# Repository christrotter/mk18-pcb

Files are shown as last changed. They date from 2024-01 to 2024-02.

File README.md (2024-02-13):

# PRODUCTION UPDATE - SUPERSEDED
This has been superseded by the rev2 of this board: [mk19](https://github.com/christrotter/mk19-pcb)

Many lessons learned.  Chief among them - it works!  We were able to prove out the shift register method.

## Things to fix
- dpad col usage; rethink how to make the dpad customizable e.g. rkjxt change-of-mind
- bad tft pinout; ordering wrong
- tft should be 0.5mm 8-pin ffc, not jst
- missing resistor arrays, 10k
- if there is a pin that could be reconfigured, ensure there is a breakout for that?
- move cyboard to edge of board
- cyboard breakout pcbs...seriously consider this; the cable lengths are super short
- main to a larger ffc cable
- per-key 0.3mm extenders pcbs...?
- change macropad vertical to edge-of-board flat FFC
- 90-deg jst, how will this help?
- and how would we make it fit?  where would things work out best to avoid the pcb capture?
- really need to make this happen
- bigger solder pads; or rather, jumpers! for the handedness, power bypass
- re-think the led bypass stuff...
- the whole bypass thing doesn’t work like i’d thought
- spare gpio breakouts should be 2.54 spaced
- what would it look like to have dual TFT?
- indicator breakout
- really needs to be DI/DO pairs per block of LEDs
- main slats
- small slats
- indicators
- then dedicated power breakouts for each
- 5v/3.3v/gnd for debug
- 5v/gnd x3 for leds
- there’s something i thought of that i didn’t write down and here we are…
- need to provide for power input
- GeorgeN suggests VSYS, not VBUS
- section 4.5 of pico datasheet
- do we want a dedicated USB power in?

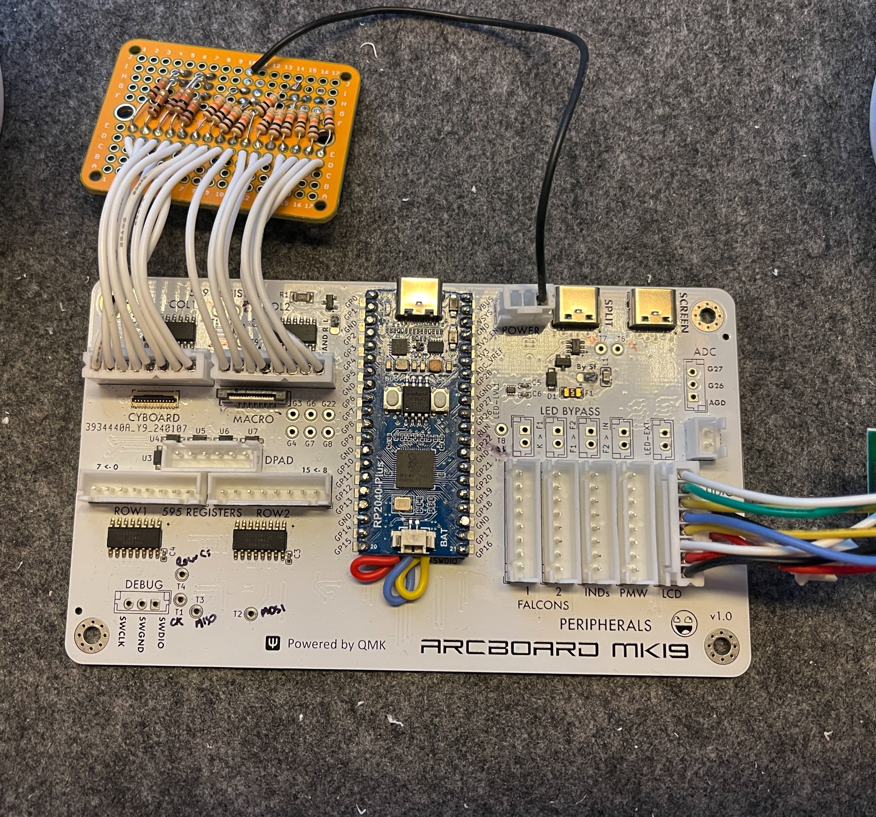
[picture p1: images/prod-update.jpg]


# mk18-pcb
The antithesis of 'keep it simple, stupid' - all the features, all the time.

Do you need to use the Cyboard flex-pcb system?  Multiple Falcon pcbs?  SPI devices?  32 pins for rows/cols?  Perhaps enough RGB to illumine your entire home?  Audio?  ADC?  Reset switch? Power and debug breakouts?  And use an existing RP Pico to do it?

Probably not, which is why I had to design my own pcb.  So here it is...

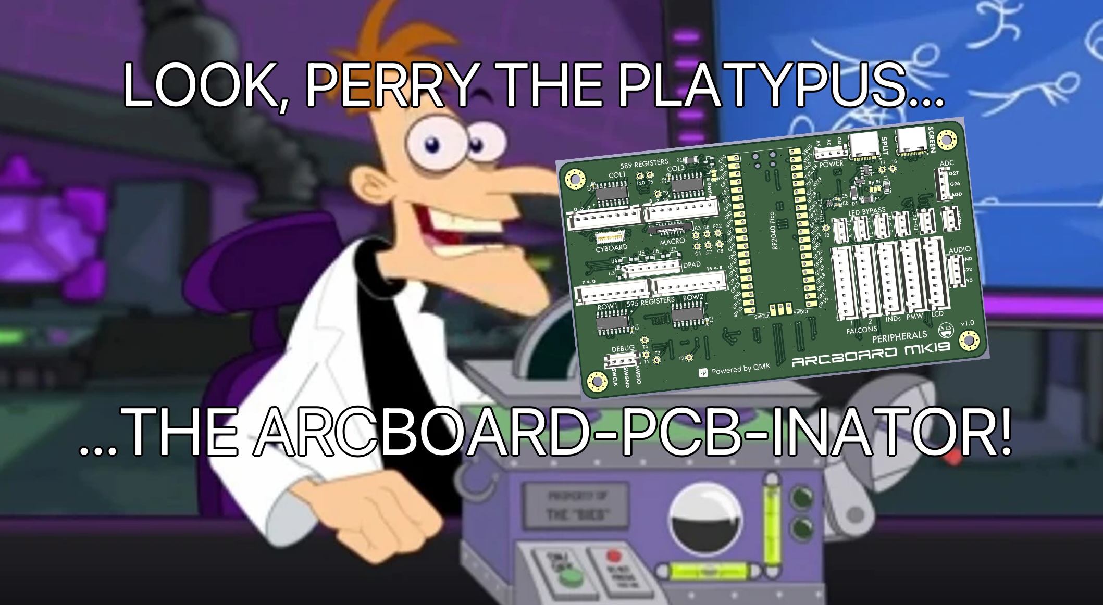
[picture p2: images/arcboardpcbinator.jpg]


# design goals
- Provide a re-usable platform for the arcboards that includes all of the normal functions
- Make it possible to use the Cyboard flex-pcb system
- Minimize pin usage by moving cols/rows over to shift registers
- Reduce the amount of fiddly soldering and wire stripping a normal hand-wire requires of you
- usb-c interconnects

## feature details
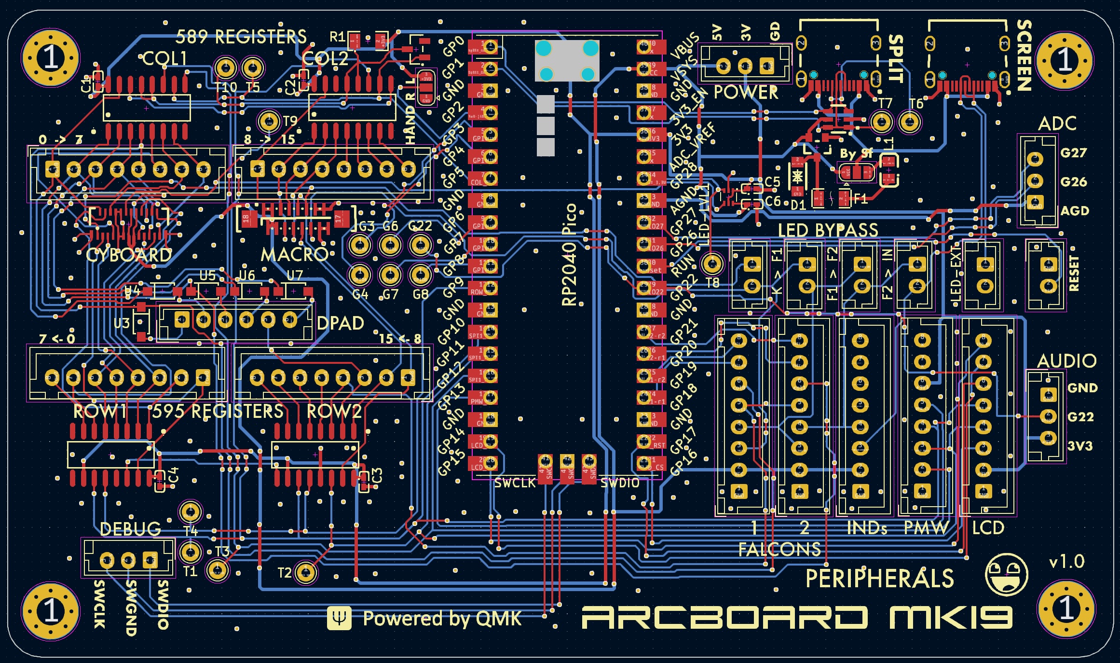
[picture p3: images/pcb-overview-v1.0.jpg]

- Raspberry PI Pico (RP2040) footprint - just add pin headers and solder away - or, solder right to pads
- keys provided through the Cyboard flex-pcb: https://www.cyboard.digital/product-page/dactyl-flex-pcbs
 - or, JST-XH 2.54 headers
- macropad using Cyboard flex-pcb keys, custom breakout pcb: https://github.com/christrotter/macropad-pcb (0.5mm pitch 16-pin FFC cable)
 - vertical FFC connector
- dpad using custom breakout pcb: https://github.com/christrotter/5way-pcb
 - diodes are configured for ROW2COL
- usb-c split connector w. tzarc-grade voltage protection
 - buuut included a solder pad jumper to bypass if needed
- split-handedness pin
- SPI breakouts
  - PMW33xx
  - LCD (e.g. GC9A01)
  - shift registers (595 for rows, 589 for cols)
- pin breakouts
 - power, debug, ADC, audio, reset
 - remaining GPIO pins
 - test points (SPI pins, serial pins, WS2818 before/after level shifting)
- led breakouts w. bypasses
 - keys
 - 2x falcon pcbs
 - indicator strip
 - screen-mounted external indicators via usb-c
 - pin for whatever else you want to add to the chain

## pcb features
- two-layer pcb w. dual ground planes tied w. vias
- components configured as per datasheets
- bypass capacitors!
- care taken to avoid power running alongside signal for too long

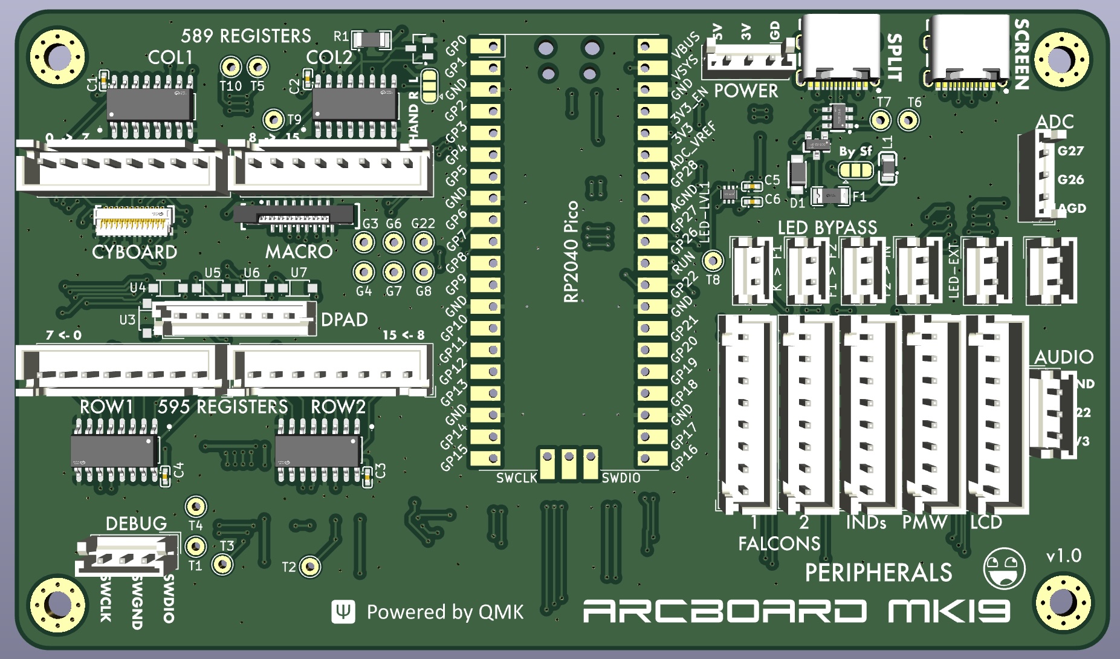
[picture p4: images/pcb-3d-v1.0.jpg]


# schematic overview
## mcu
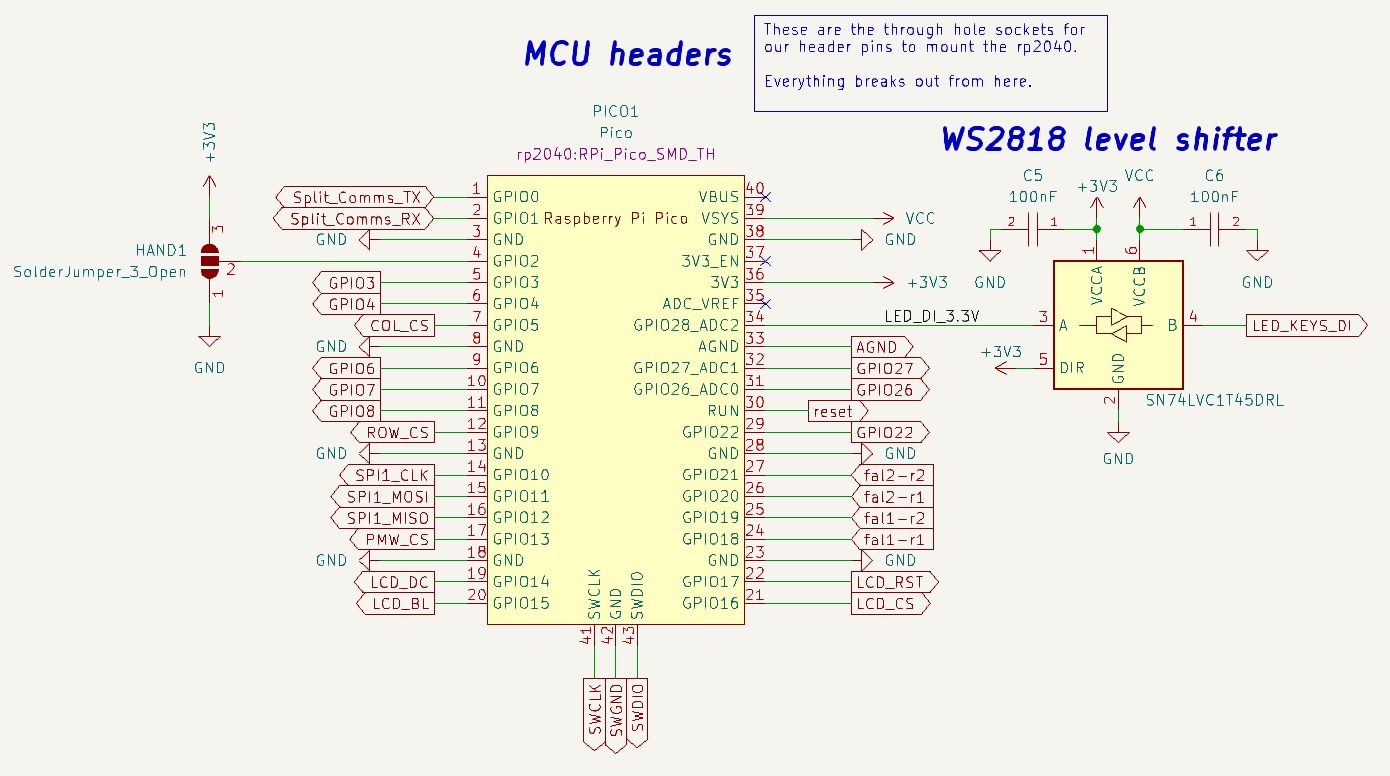
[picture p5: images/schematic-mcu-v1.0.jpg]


## keys
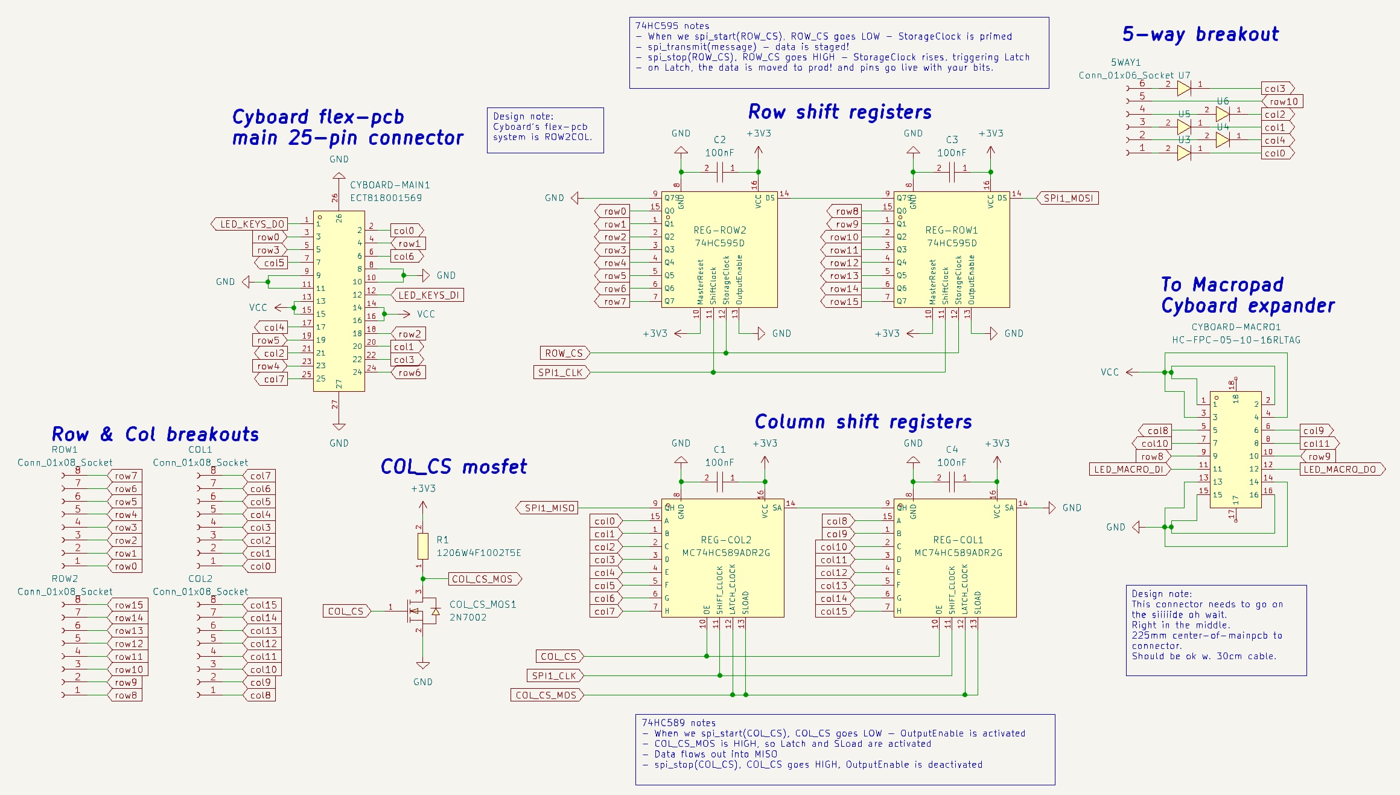
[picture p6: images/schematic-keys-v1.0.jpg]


## peripherals
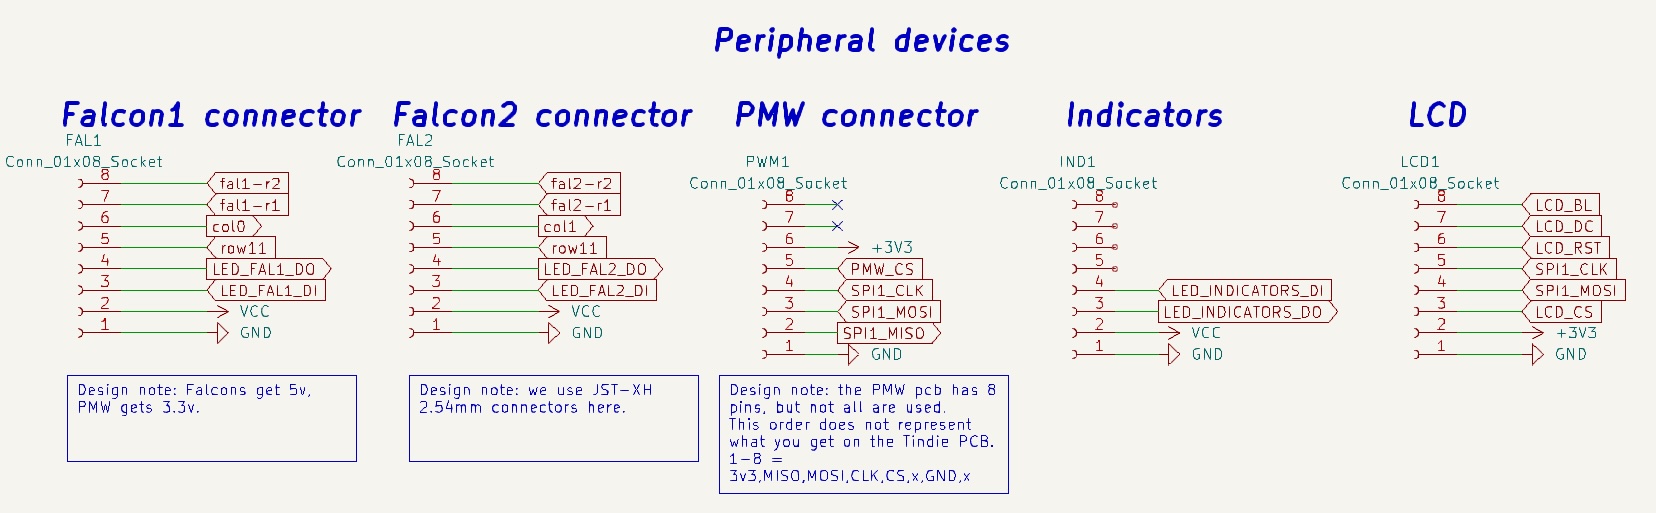
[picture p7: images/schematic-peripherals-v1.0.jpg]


## usb connections
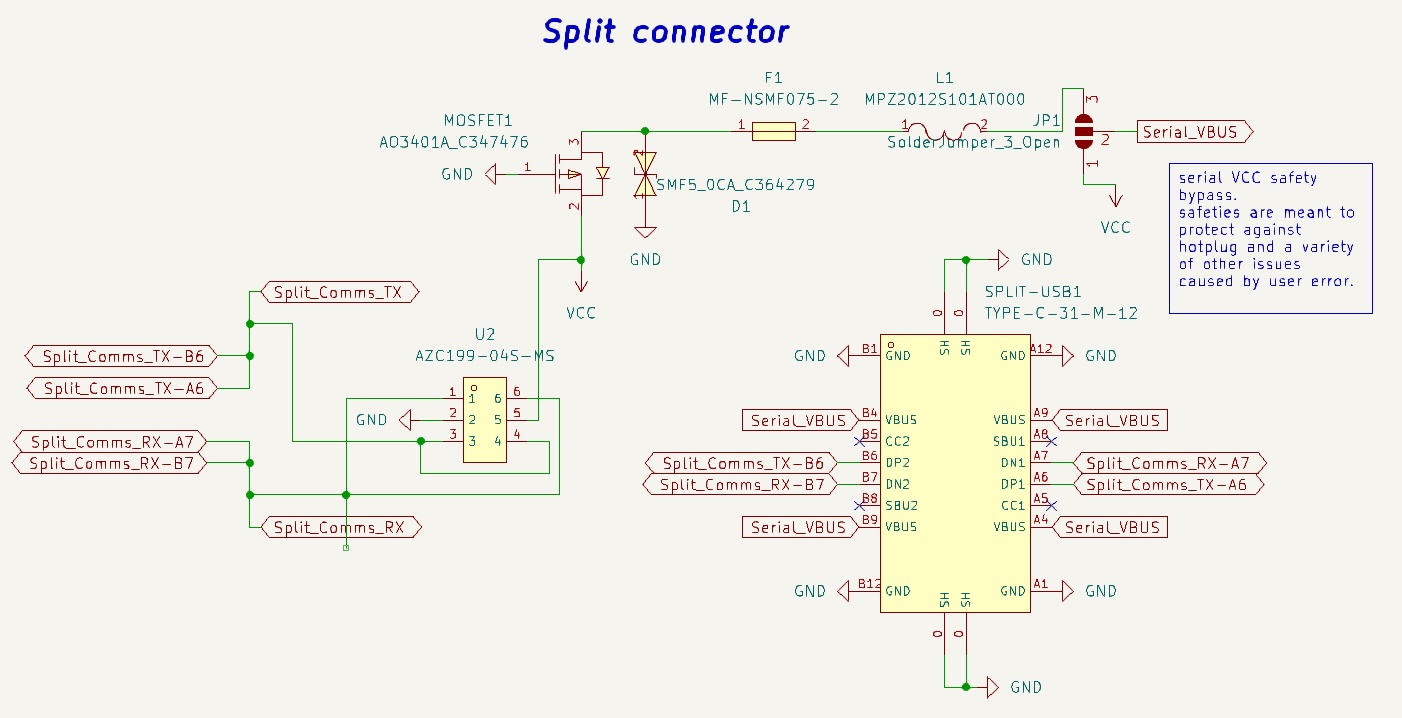
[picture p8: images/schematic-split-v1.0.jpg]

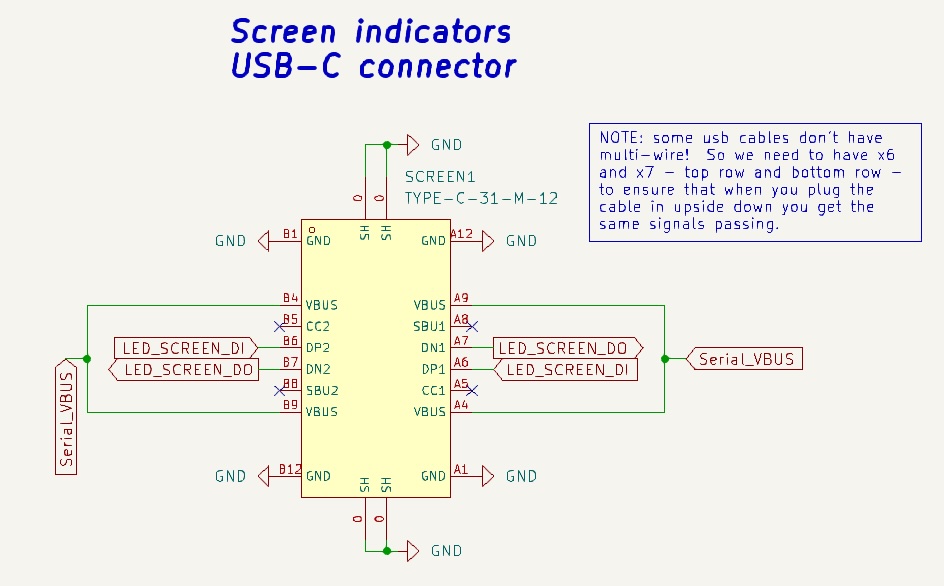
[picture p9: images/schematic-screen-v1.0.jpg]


## breakouts
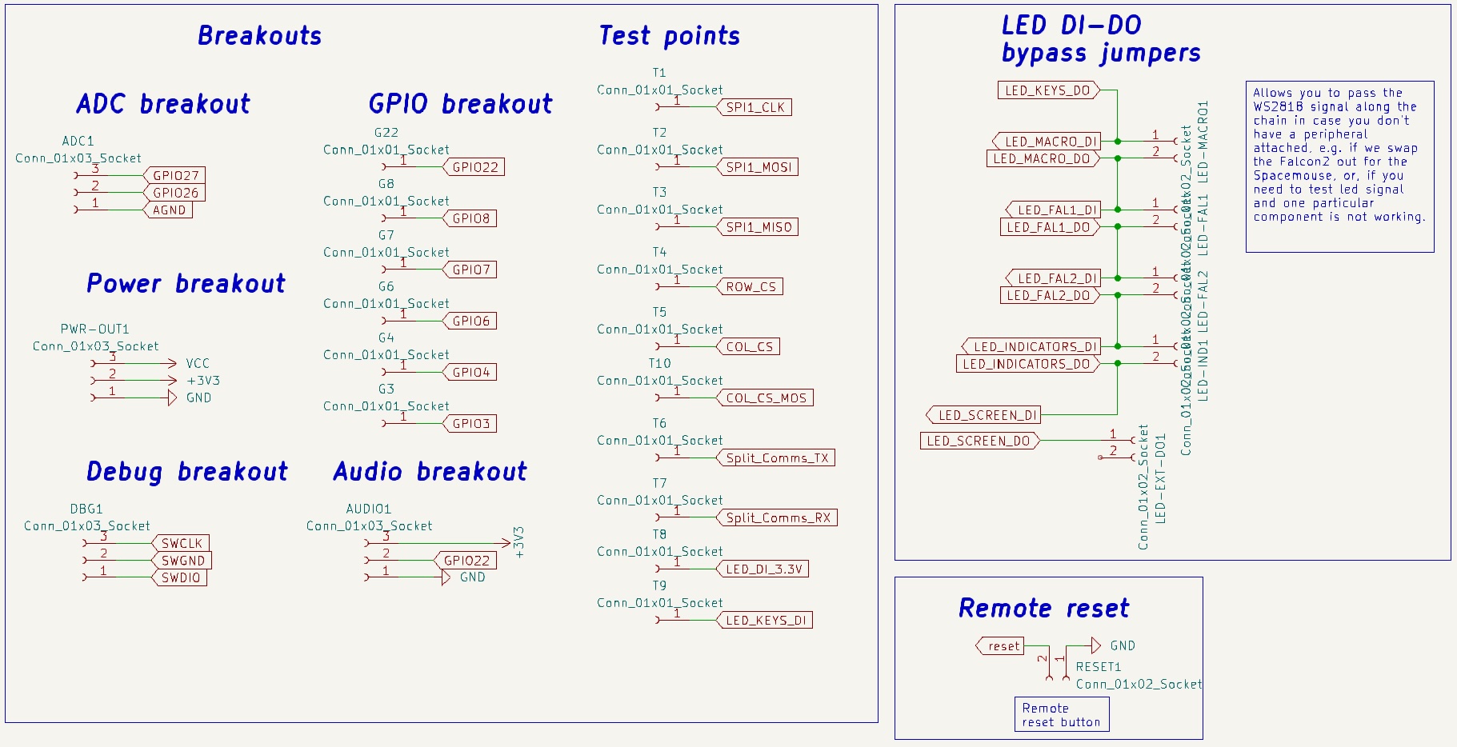
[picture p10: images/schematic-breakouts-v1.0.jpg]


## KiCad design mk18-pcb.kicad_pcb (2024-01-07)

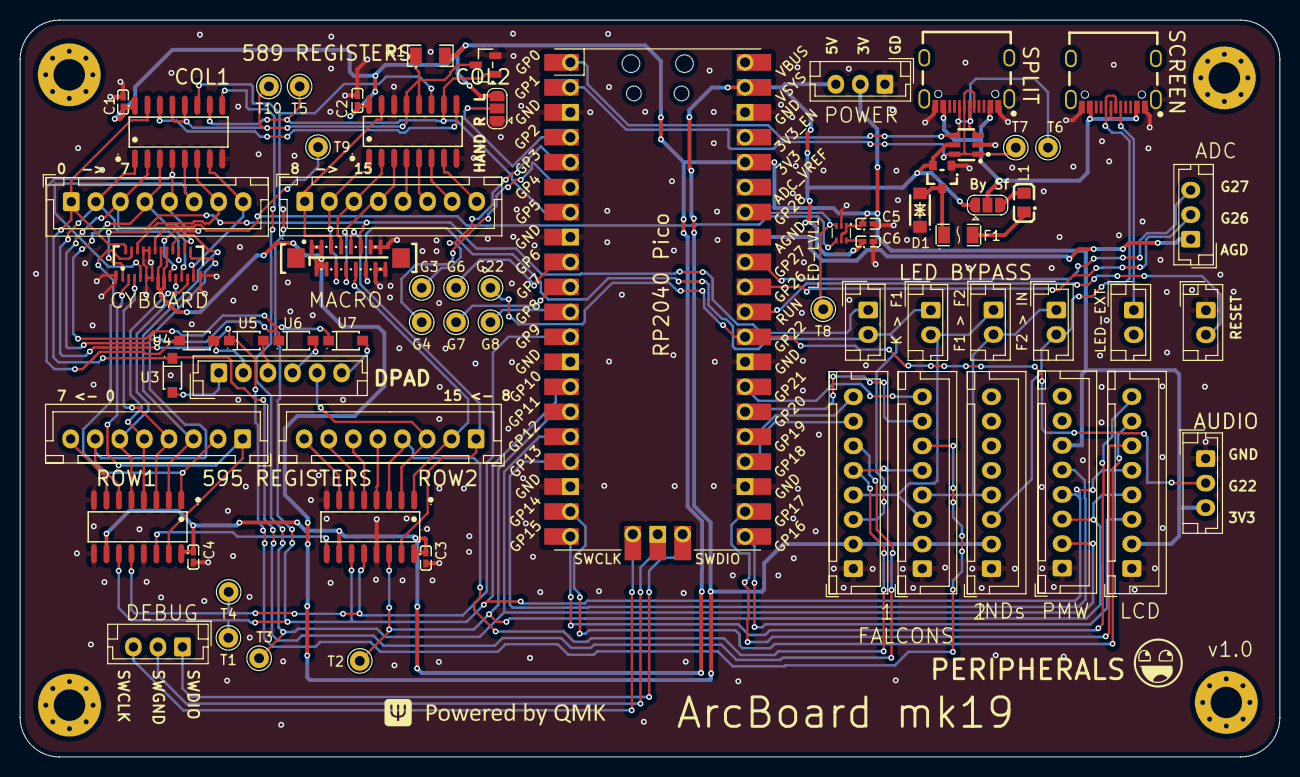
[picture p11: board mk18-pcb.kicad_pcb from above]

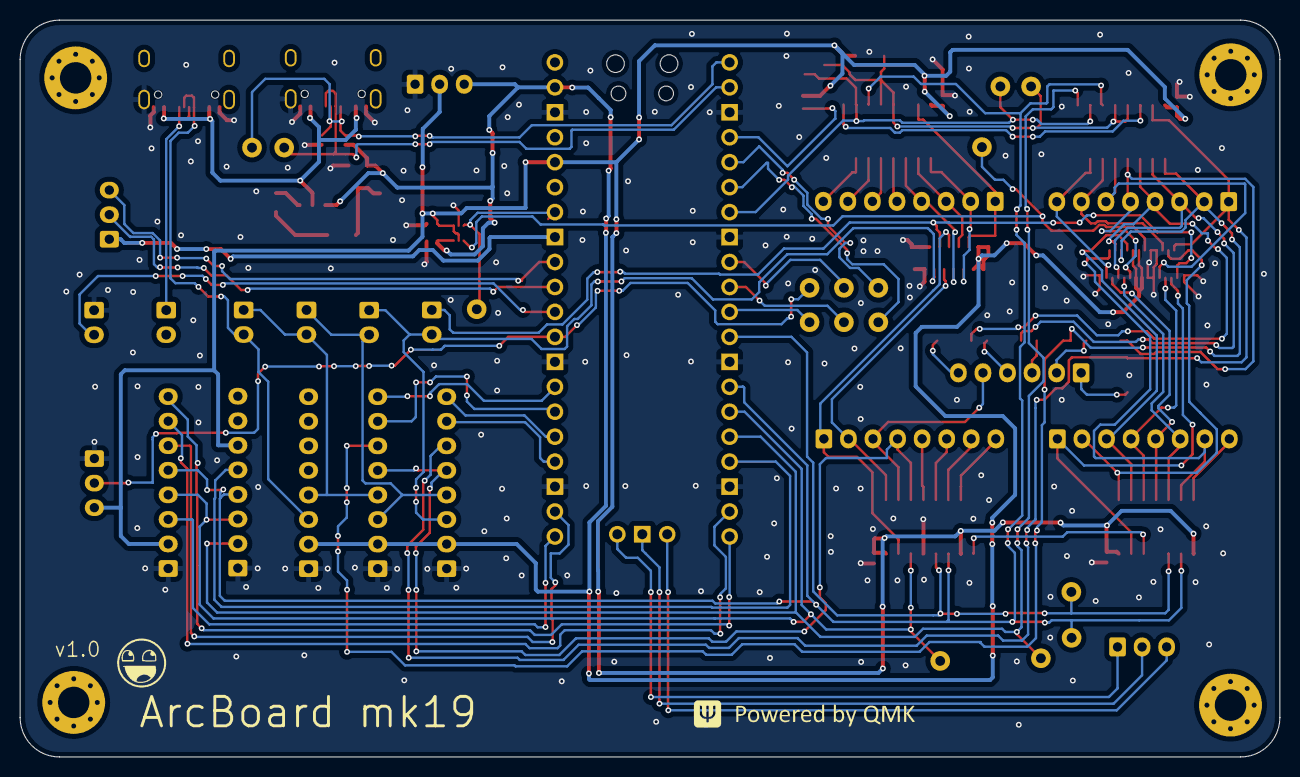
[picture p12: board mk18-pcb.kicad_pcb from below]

Board: 2 copper layers, 128.2 x 75.0 mm, 74 parts (2 on the bottom side), 85 nets.

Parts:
5WAY1: Conn_01x06_Socket; JST_EH_B6B-EH-A_1x06_P2.50mm_Vertical
ADC1: Conn_01x03_Socket; JST_EH_B3B-EH-A_1x03_P2.50mm_Vertical
AUDIO1: Conn_01x03_Socket; JST_EH_B3B-EH-A_1x03_P2.50mm_Vertical
C1, C2, C3, C4, C5, C6: 100nF; C0402
COL1, COL2: Conn_01x08_Socket; JST_XH_B8B-XH-A_1x08_P2.50mm_Vertical
COL_CS_MOS1: 2N7002; SOT-23-3_L2.9-W1.3-P1.90-LS2.4-BR
CYBOARD-MACRO1: HC-FPC-05-10-16RLTAG; FPC-SMD_16P-P0.50_HDGC_0.5K-A-16PBF
CYBOARD-MAIN1: ECT818001569; FPC-SMD_ECT818001569
D1: SMF5_0CA_C364279; SOD-123FL_L2.8-W1.8-LS3.7-BI
DBG1: Conn_01x03_Socket; JST_EH_B3B-EH-A_1x03_P2.50mm_Vertical
F1: MF-NSMF075-2; F1206
FAL1, FAL2: Conn_01x08_Socket; JST_XH_B8B-XH-A_1x08_P2.50mm_Vertical
G3, G4, G6, G7, G8, G22: Conn_01x01_Socket; Pin_D1.0mm_L10.0mm
H1, H2, H3, H4: MountingHole; MountingHole_3.2mm_M3_Pad_Via
HAND1: SolderJumper_3_Open; SolderJumper-3_P1.3mm_Open_RoundedPad1.0x1.5mm
IND1: Conn_01x08_Socket; JST_XH_B8B-XH-A_1x08_P2.50mm_Vertical
JP1: SolderJumper_3_Open; SolderJumper-3_P1.3mm_Open_RoundedPad1.0x1.5mm
L1: MPZ2012S101AT000; L0805
LCD1: Conn_01x08_Socket; JST_XH_B8B-XH-A_1x08_P2.50mm_Vertical
LED-EXT-DO1: Conn_01x02_Socket; JST_EH_B2B-EH-A_1x02_P2.50mm_Vertical
LED-FAL1, LED-FAL2: Conn_01x02_Socket; JST_EH_B2B-EH-A_1x02_P2.50mm_Vertical
LED-IND1: Conn_01x02_Socket; JST_EH_B2B-EH-A_1x02_P2.50mm_Vertical
LED-LVL1: SN74LVC1T45DRL; SOT-563_L1.6-W1.2-P0.50-LS1.6-BR
LED-MACRO1: Conn_01x02_Socket; JST_EH_B2B-EH-A_1x02_P2.50mm_Vertical
LOGO1, LOGO2: **REF; awesome-logo
LOGO3, LOGO4: **REF; qmk-lite
MOSFET1: AO3401A_C347476; SOT-23_L2.9-W1.3-P1.90-LS2.4-BR
PICO1: Pico; RPi_Pico_SMD_TH
PWM1: Conn_01x08_Socket; JST_XH_B8B-XH-A_1x08_P2.50mm_Vertical
PWR-OUT1: Conn_01x03_Socket; JST_EH_B3B-EH-A_1x03_P2.50mm_Vertical
R1: 1206W4F1002T5E; R1206
REG-COL1, REG-COL2: MC74HC589ADR2G; SOIC-16_L9.9-W3.9-P1.27-LS6.0-BL
REG-ROW1, REG-ROW2: 74HC595D; SOIC-16_L9.9-W3.9-P1.27-LS6.0-BL
RESET1: Conn_01x02_Socket; JST_EH_B2B-EH-A_1x02_P2.50mm_Vertical
ROW1, ROW2: Conn_01x08_Socket; JST_XH_B8B-XH-A_1x08_P2.50mm_Vertical
SCREEN1: TYPE-C-31-M-12; USB-C_SMD-TYPE-C-31-M-12
SPLIT-USB1: TYPE-C-31-M-12; USB-C_SMD-TYPE-C-31-M-12
T1, T2, T3, T4, T5, T6, T7, T8, T9, T10: Conn_01x01_Socket; Pin_D1.0mm_L10.0mm
U2: AZC199-04S-MS; TSOT-23-6_L2.9-W1.6-P0.95-LS2.8-BL
U3, U4, U5, U6, U7: 1N4148W_C81598; SOD-123F_L2.7-W1.6-LS3.8-RD

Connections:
+3V3: AUDIO1.3, C1.1, C2.1, C3.1, C4.1, C5.1, HAND1.3 (B), LCD1.2, LED-LVL1.1 (VCCA), LED-LVL1.5 (DIR), PICO1.36 (3V3), PWM1.6, PWR-OUT1.2, R1.2, REG-COL1.16 (VCC), REG-COL2.16 (VCC), REG-ROW1.10 (MasterReset), REG-ROW1.16 (VCC), REG-ROW2.10 (MasterReset), REG-ROW2.16 (VCC)
AGND: ADC1.1, PICO1.33 (AGND)
COL_CS: COL_CS_MOS1.1 (G), PICO1.7 (GPIO5), REG-COL1.10 (OE), REG-COL2.10 (OE), T5.1
COL_CS_MOS: COL_CS_MOS1.3 (D), R1.1, REG-COL1.12 (LATCH_CLOCK), REG-COL1.13 (SLOAD), REG-COL2.12 (LATCH_CLOCK), REG-COL2.13 (SLOAD), T10.1
GND: AUDIO1.1, C1.2, C2.2, C3.2, C4.2, C5.2, C6.2, COL_CS_MOS1.2 (S), CYBOARD-MACRO1.13, CYBOARD-MACRO1.14, CYBOARD-MACRO1.15, CYBOARD-MACRO1.16, CYBOARD-MAIN1.8, CYBOARD-MAIN1.9, CYBOARD-MAIN1.10, CYBOARD-MAIN1.11, CYBOARD-MAIN1.26, CYBOARD-MAIN1.27, D1.1 (K), FAL1.1, FAL2.1, HAND1.1 (A), IND1.1, LCD1.1, LED-LVL1.2 (GND), MOSFET1.1 (G), PICO1.3 (GND), PICO1.8 (GND), PICO1.13 (GND), PICO1.18 (GND), PICO1.23 (GND), PICO1.28 (GND), PICO1.38 (GND), PWM1.1, PWR-OUT1.1, REG-COL1.8 (GND), REG-COL1.14 (SA), REG-COL2.8 (GND), REG-ROW1.8 (GND), REG-ROW1.13 (OutputEnable), REG-ROW2.8 (GND), REG-ROW2.9 (Q7S), REG-ROW2.13 (OutputEnable), RESET1.1, SCREEN1.0 (SH), SCREEN1.A1 (GND), SCREEN1.A12 (GND), SCREEN1.B1 (GND), SCREEN1.B12 (GND), SPLIT-USB1.0 (SH), SPLIT-USB1.A1 (GND), SPLIT-USB1.A12 (GND), SPLIT-USB1.B1 (GND), SPLIT-USB1.B12 (GND), U2.2
GPIO3: G3.1, PICO1.5 (GPIO3)
GPIO4: G4.1, PICO1.6 (GPIO4)
GPIO6: G6.1, PICO1.9 (GPIO6)
GPIO7: G7.1, PICO1.10 (GPIO7)
GPIO8: G8.1, PICO1.11 (GPIO8)
GPIO22: AUDIO1.2, G22.1, PICO1.29 (GPIO22)
GPIO26: ADC1.2, PICO1.31 (GPIO26_ADC0)
GPIO27: ADC1.3, PICO1.32 (GPIO27_ADC1)
LCD_BL: LCD1.8, PICO1.20 (GPIO15)
LCD_CS: LCD1.3, PICO1.21 (GPIO16)
LCD_DC: LCD1.7, PICO1.19 (GPIO14)
LCD_RST: LCD1.6, PICO1.22 (GPIO17)
LED_DI_3.3V: LED-LVL1.3 (A), PICO1.34 (GPIO28_ADC2), T8.1
LED_FAL1_DI: CYBOARD-MACRO1.12, FAL1.3, LED-FAL1.1, LED-MACRO1.2
LED_FAL1_DO: FAL1.4, FAL2.3, LED-FAL1.2, LED-FAL2.1
LED_FAL2_DO: FAL2.4, IND1.4, LED-FAL2.2, LED-IND1.1
LED_INDICATORS_DO: IND1.3, LED-IND1.2, SCREEN1.A6 (DP1), SCREEN1.B6 (DP2)
LED_KEYS_DI: CYBOARD-MAIN1.12, LED-LVL1.4 (B), T9.1
LED_KEYS_DO: CYBOARD-MACRO1.11, CYBOARD-MAIN1.1, LED-MACRO1.1
LED_SCREEN_DO: LED-EXT-DO1.1, SCREEN1.A7 (DN1), SCREEN1.B7 (DN2)
unnamed: 5WAY1.1, U3.2 (A)
unnamed: 5WAY1.2, U4.2 (A)
unnamed: 5WAY1.3, U5.2 (A)
unnamed: 5WAY1.4, U6.2 (A)
unnamed: 5WAY1.6, U7.2 (A)
unnamed: D1.2 (A), F1.1, MOSFET1.3 (D)
unnamed: F1.2, L1.1
unnamed: HAND1.2 (C), PICO1.4 (GPIO2)
unnamed: JP1.3 (B), L1.2
unnamed: REG-COL1.9 (QH), REG-COL2.14 (SA)
unnamed: REG-ROW1.9 (Q7S), REG-ROW2.14 (DS)
PMW_CS: PICO1.17 (GPIO13), PWM1.5
ROW_CS: PICO1.12 (GPIO9), REG-ROW1.12 (StorageClock), REG-ROW2.12 (StorageClock), T4.1
SPI1_CLK: LCD1.5, PICO1.14 (GPIO10), PWM1.4, REG-COL1.11 (SHIFT_CLOCK), REG-COL2.11 (SHIFT_CLOCK), REG-ROW1.11 (ShiftClock), REG-ROW2.11 (ShiftClock), T1.1
SPI1_MISO: PICO1.16 (GPIO12), PWM1.2, REG-COL2.9 (QH), T3.1
SPI1_MOSI: LCD1.4, PICO1.15 (GPIO11), PWM1.3, REG-ROW1.14 (DS), T2.1
SWCLK: DBG1.3, PICO1.41 (SWCLK)
SWDIO: DBG1.1, PICO1.43 (SWDIO)
SWGND: DBG1.2, PICO1.42 (GND)
Serial_VBUS: JP1.2 (C), SCREEN1.A4 (VBUS), SCREEN1.A9 (VBUS), SCREEN1.B4 (VBUS), SCREEN1.B9 (VBUS), SPLIT-USB1.A4 (VBUS), SPLIT-USB1.A9 (VBUS), SPLIT-USB1.B4 (VBUS), SPLIT-USB1.B9 (VBUS)
Split_Comms_RX: PICO1.2 (GPIO1), SPLIT-USB1.A7 (DN1), SPLIT-USB1.B7 (DN2), T7.1, U2.1, U2.6
Split_Comms_TX: PICO1.1 (GPIO0), SPLIT-USB1.A6 (DP1), SPLIT-USB1.B6 (DP2), T6.1, U2.3, U2.4
VCC: C6.1, CYBOARD-MACRO1.1, CYBOARD-MACRO1.2, CYBOARD-MACRO1.3, CYBOARD-MACRO1.4, CYBOARD-MAIN1.13, CYBOARD-MAIN1.14, CYBOARD-MAIN1.15, CYBOARD-MAIN1.16, FAL1.2, FAL2.2, IND1.2, JP1.1 (A), LED-LVL1.6 (VCCB), MOSFET1.2 (S), PICO1.39 (VSYS), PWR-OUT1.3, U2.5
col0: COL1.1, CYBOARD-MAIN1.2, FAL1.6, REG-COL2.15 (A), U3.1 (K)
col1: COL1.2, CYBOARD-MAIN1.20, FAL2.6, REG-COL2.1 (B), U5.1 (K)
col2: COL1.3, CYBOARD-MAIN1.21, REG-COL2.2 (C), U6.1 (K)
col3: COL1.4, CYBOARD-MAIN1.22, REG-COL2.3 (D), U7.1 (K)
col4: COL1.5, CYBOARD-MAIN1.17, REG-COL2.4 (E), U4.1 (K)
col5: COL1.6, CYBOARD-MAIN1.7, REG-COL2.5 (F)
col6: COL1.7, CYBOARD-MAIN1.6, REG-COL2.6 (G)
col7: COL1.8, CYBOARD-MAIN1.25, REG-COL2.7 (H)
col8: COL2.1, CYBOARD-MACRO1.5, REG-COL1.15 (A)
col9: COL2.2, CYBOARD-MACRO1.6, REG-COL1.1 (B)
col10: COL2.3, CYBOARD-MACRO1.7, REG-COL1.2 (C)
col11: COL2.4, CYBOARD-MACRO1.8, REG-COL1.3 (D)
col12: COL2.5, REG-COL1.4 (E)
col13: COL2.6, REG-COL1.5 (F)
col14: COL2.7, REG-COL1.6 (G)
col15: COL2.8, REG-COL1.7 (H)
fal1-r1: FAL1.7, PICO1.24 (GPIO18)
fal1-r2: FAL1.8, PICO1.25 (GPIO19)
fal2-r1: FAL2.7, PICO1.26 (GPIO20)
fal2-r2: FAL2.8, PICO1.27 (GPIO21)
reset: PICO1.30 (RUN), RESET1.2
row0: CYBOARD-MAIN1.3, REG-ROW2.15 (Q0), ROW1.1
row1: CYBOARD-MAIN1.4, REG-ROW2.1 (Q1), ROW1.2
row2: CYBOARD-MAIN1.18, REG-ROW2.2 (Q2), ROW1.3
row3: CYBOARD-MAIN1.5, REG-ROW2.3 (Q3), ROW1.4
row4: CYBOARD-MAIN1.23, REG-ROW2.4 (Q4), ROW1.5
row5: CYBOARD-MAIN1.19, REG-ROW2.5 (Q5), ROW1.6
row6: CYBOARD-MAIN1.24, REG-ROW2.6 (Q6), ROW1.7
row7: REG-ROW2.7 (Q7), ROW1.8
row8: CYBOARD-MACRO1.9, REG-ROW1.15 (Q0), ROW2.1
row9: CYBOARD-MACRO1.10, REG-ROW1.1 (Q1), ROW2.2
row10: 5WAY1.5, REG-ROW1.2 (Q2), ROW2.3
row11: FAL1.5, FAL2.5, REG-ROW1.3 (Q3), ROW2.4
row12: REG-ROW1.4 (Q4), ROW2.5
row13: REG-ROW1.5 (Q5), ROW2.6
row14: REG-ROW1.6 (Q6), ROW2.7
row15: REG-ROW1.7 (Q7), ROW2.8

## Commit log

2023-11-19 initial commit of mk18-pcb files
    [mk18-pcb-CuBottom.gbr, mk18-pcb-CuTop.gbr, mk18-pcb-EdgeCuts.gbr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]
2023-12-29 adding some shift register info and other stuff
    [mk18-pcb.kicad_sch]
2023-12-29 flipping mosi on cols
    [mk18-pcb.kicad_sch]
2023-12-30 cleaning up save state
    [mk18-pcb.kicad_sch]
2023-12-31 capturing updates for the day
    [mk18-pcb.kicad_sch]
2024-01-01 work from the 31st
    [mk18-pcb.kicad_sch]
2024-01-03 jan2 updates, relocating shift registers
    [mk18-pcb.kicad_pcb, mk18-pcb.kicad_sch]
2024-01-03 adding design rules and jan3 updates. needs review now.
    [mk18-pcb.kicad_pcb]
2024-01-04 getting ready to re-do the shift register routing so we can have pinouts.
    [mk18-pcb.kicad_pcb, mk18-pcb.kicad_sch]
2024-01-05 jan4 updates
    [mk18-pcb.kicad_pcb, mk18-pcb.kicad_sch]
2024-01-05 added bypass for safeties
    [mk18-pcb.kicad_pcb, mk18-pcb.kicad_sch]
2024-01-05 prior to removing pull-up resistors on comms
    [mk18-pcb.kicad_pcb, mk18-pcb.kicad_sch]
2024-01-06 jan6 updates, added 5way, moved all vias off silkscreen, added breakouts
    [mk18-pcb.kicad_pcb, mk18-pcb.kicad_sch]
2024-01-06 really close now maybe kinda
    [mk18-pcb.kicad_pcb, mk18-pcb.kicad_sch]
2024-01-06 added debug, test points, more
    [mk18-pcb.kicad_pcb, mk18-pcb.kicad_sch]
2024-01-06 preparing to redo some parts
    [mk18-pcb.kicad_pcb]
2024-01-06 before updating the macropad connector
    [mk18-pcb.kicad_pcb, mk18-pcb.kicad_sch]
2024-01-06 replace two parts
    [mk18-pcb.kicad_pcb, mk18-pcb.kicad_sch]
2024-01-06 final commits, changing to some basic parts
    [mk18-pcb.kicad_pcb, mk18-pcb.kicad_sch]
2024-01-07 final production version of 1.0 woooo
    [mk18-pcb.kicad_pcb, mk18-pcb.kicad_sch]
2024-01-07 updating readme, tidied up schematic
    [mk18-pcb.kicad_pcb, mk18-pcb.kicad_sch]
